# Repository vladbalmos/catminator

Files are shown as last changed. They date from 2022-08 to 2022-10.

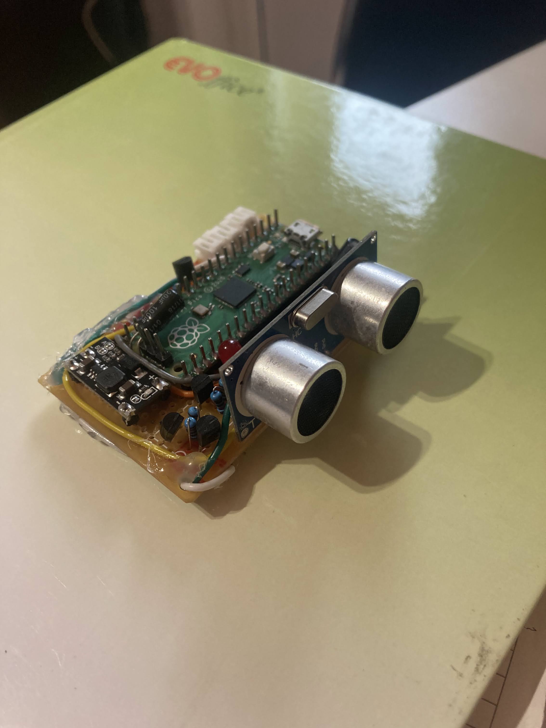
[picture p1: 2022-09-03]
docs/perfboard.jpg

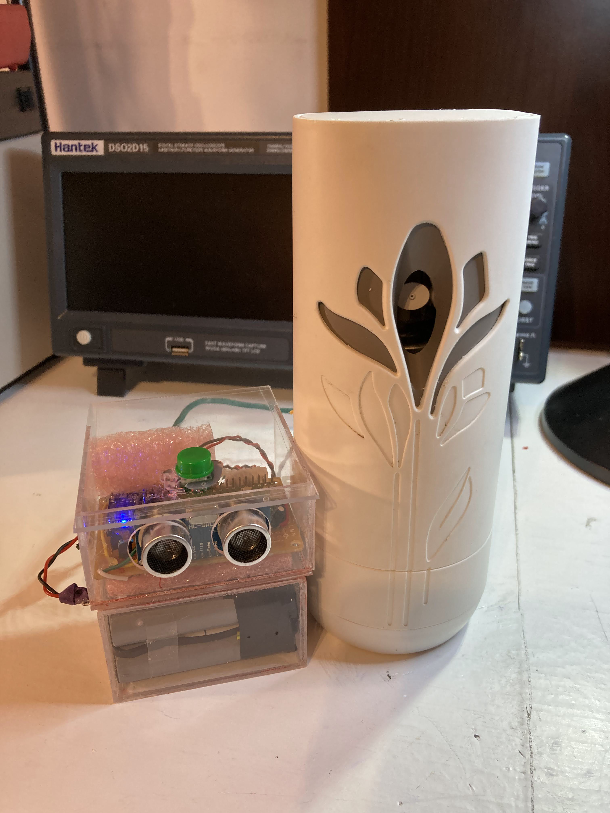
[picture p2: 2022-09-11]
docs/final-prototype.jpg

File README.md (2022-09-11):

# About
This is an educational Raspberry Pico project.  
The Pico makes use of a distance sensor to detect any objects/animals/human (preferably a cat) then drives the motors (TP7 & TP8) of an AirWick unit to spray the detected object in the hopes to scare it away.

Components: 

    - Distance sensor (HC-SR04)
    - AirWick Freshmatic (Code: ARW00171)
    - Raspberry Pico
    - 3.7V Lithium battery
    - 3V to 5V DC boost IC

For the full components list see the circuit schematic [docs/schematic.png](https://github.com/vladbalmos/catminator/blob/master/docs/schematic.png).  
To see which points on the AirWick's PCB need to be connected to the Pico see [docs/airwick-connections.png](https://github.com/vladbalmos/catminator/blob/master/docs/airwick-connections.png).

Thank you BigClive for reverse engineering the AirWick. [https://www.youtube.com/watch?v=4OC4U6FiJus](https://www.youtube.com/watch?v=4OC4U6FiJus).

Power usage:  

    - ~180ma (with motors active)
    - ~25ma (while scanning for targets)
    - ~12ma (standby)

## Memento

Monitoring serial port: 

    minicom -o -D /dev/ttyACM0 -b 115200

Building: 

    make debug #debug version
    make build #release version

Deploy: 

    make install-debug #debug version
    make install #release version

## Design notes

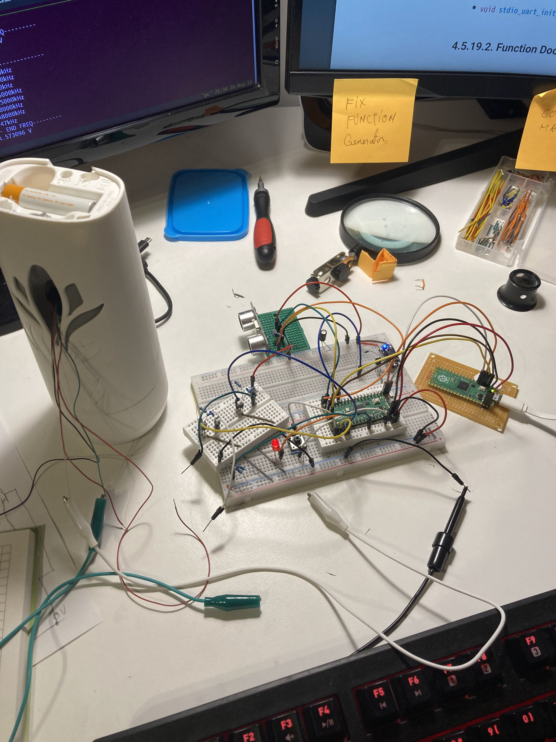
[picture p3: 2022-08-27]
docs/breadboard-prototype.jpg

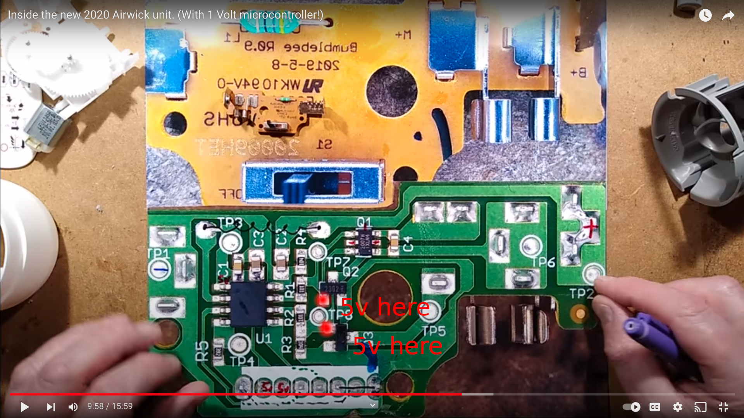
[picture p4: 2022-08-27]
docs/airwick-connections.png

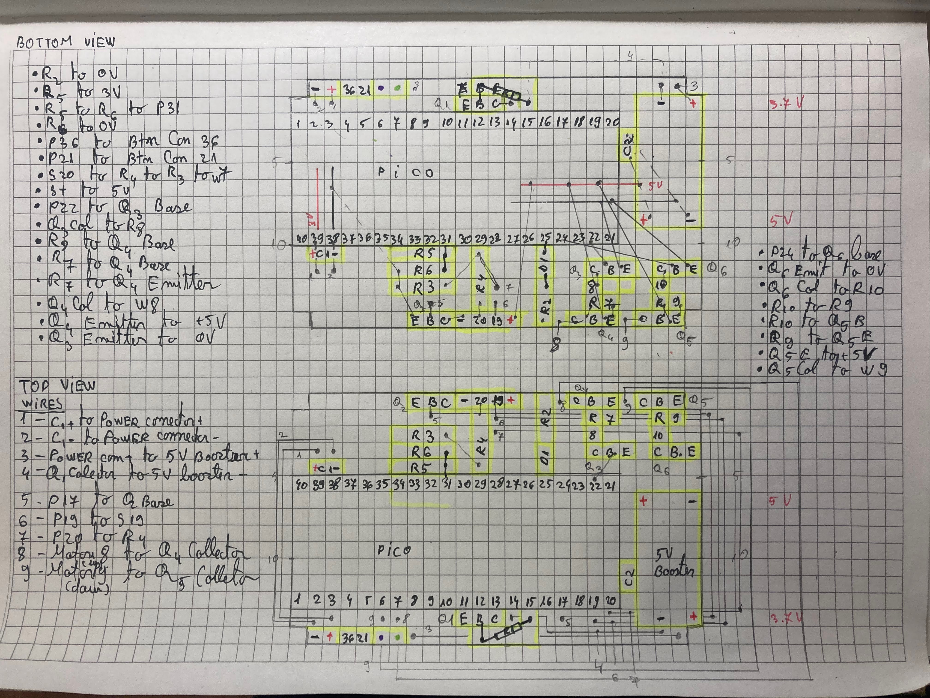
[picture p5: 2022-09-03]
docs/perfboard-layout.jpg

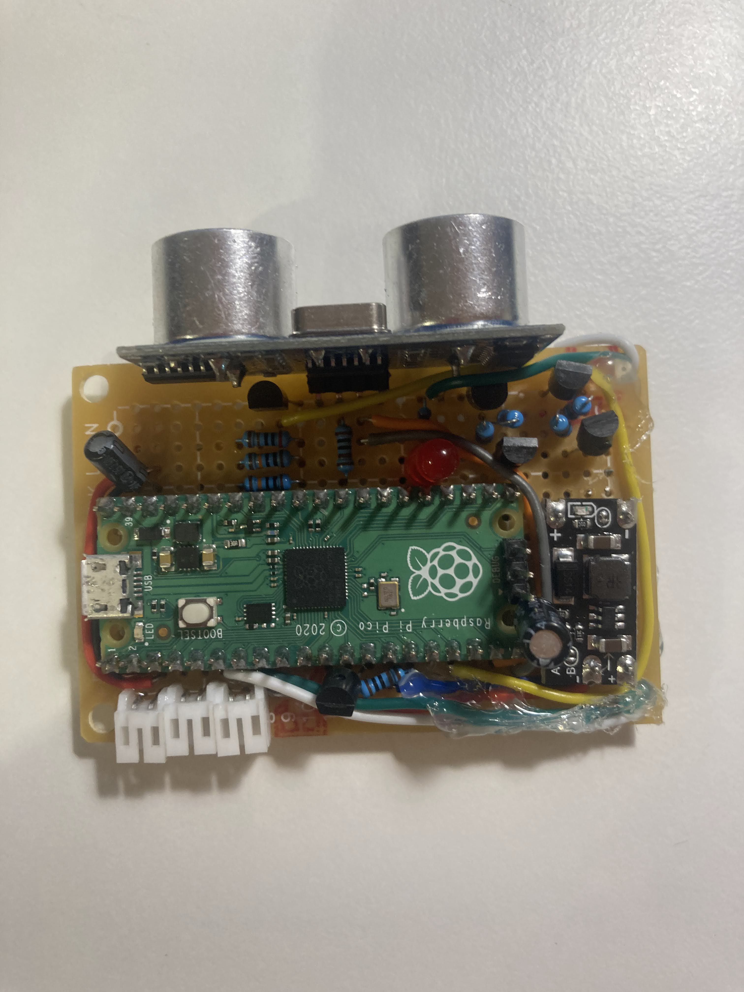
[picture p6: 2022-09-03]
docs/perfboard-side-up.jpg

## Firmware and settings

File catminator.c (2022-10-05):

/**
 * Copyright (c) 2022 Vlad Balmos
 *
 * SPDX-License-Identifier: MIT License
 */

#include <stdio.h>
#include "pico/stdlib.h"
#include "pico/util/queue.h"
#include "pico/multicore.h"
#include "hardware/pll.h"
#include "hardware/clocks.h"
#include "hardware/xosc.h"
#include "hardware/structs/pll.h"
#include "hardware/structs/clocks.h"
#include "utils.h"
#include "sensor.h"
#include "motor.h"
#include "battery.h"

#define COOL_OFF_PERIOD 10 * 1000 // seconds
#define MOTOR_DRIVE_DELAY 5000
#define DEFAULT_LOOP_SLEEP 1000
#define MAX_TARGET_DISTANCE 50 // cm

// Pins
#define SENSOR_POWER_PIN 13
#define SENSOR_INPUT_PIN 14
#define SENSOR_REPLY_PIN 15
#define BTN_CANCEL_TRIGGER_PIN 16
#define MOTOR_UP_PIN 17
#define MOTOR_DOWN_PIN 18
#define STATUS_LED_PIN 19
#define BOOST_5V_ENABLE_PIN 11

queue_t sensor_request_q;
queue_t sensor_response_q;
absolute_time_t cool_off;
bool clear_motor_drive_alarm = false;


void core1_entry() {
    while (true) {
        bool request;
        int64_t response = -1;

        queue_remove_blocking(&sensor_request_q, &request);

        if (!request) {
            sleep_ms(100);
            continue;
        }

        absolute_time_t start = nil_time;
        absolute_time_t end = nil_time;

        sensor_trigger_echo();
        sensor_measure_reply(&start, &end);

        if (start != nil_time && end != nil_time) {
            response = absolute_time_diff_us(start, end);
        }
        queue_add_blocking(&sensor_response_q, &response);
    }
}

bool is_cooling_off() {
    return cool_off != nil_time && absolute_time_diff_us(get_absolute_time(), cool_off) > 0;
}

void gpio_callback(uint gpio, uint32_t events) {
    if (gpio == BTN_CANCEL_TRIGGER_PIN && !is_cooling_off()) {
        clear_motor_drive_alarm = true;
        return;
    }
}

void measure_freqs(void) {
    uint f_pll_sys = frequency_count_khz(CLOCKS_FC0_SRC_VALUE_PLL_SYS_CLKSRC_PRIMARY);
    uint f_pll_usb = frequency_count_khz(CLOCKS_FC0_SRC_VALUE_PLL_USB_CLKSRC_PRIMARY);
    uint f_rosc = frequency_count_khz(CLOCKS_FC0_SRC_VALUE_ROSC_CLKSRC);
    uint f_clk_sys = frequency_count_khz(CLOCKS_FC0_SRC_VALUE_CLK_SYS);
    uint f_clk_peri = frequency_count_khz(CLOCKS_FC0_SRC_VALUE_CLK_PERI);
    uint f_clk_usb = frequency_count_khz(CLOCKS_FC0_SRC_VALUE_CLK_USB);
    uint f_clk_adc = frequency_count_khz(CLOCKS_FC0_SRC_VALUE_CLK_ADC);
    uint f_clk_rtc = frequency_count_khz(CLOCKS_FC0_SRC_VALUE_CLK_RTC);

    printf("------------------- FREQ-------------\n");
    printf("\tll_sys  = %dkHz\n", f_pll_sys);
    printf("\tpll_usb  = %dkHz\n", f_pll_usb);
    printf("\trosc     = %dkHz\n", f_rosc);
    printf("\tclk_sys  = %dkHz\n", f_clk_sys);
    printf("\tclk_peri = %dkHz\n", f_clk_peri);
    printf("\tclk_usb  = %dkHz\n", f_clk_usb);
    printf("\tclk_adc  = %dkHz\n", f_clk_adc);
    printf("\tclk_rtc  = %dkHz\n", f_clk_rtc);
    printf("------------------- END FREQ---------\n");
}

void stop() {
    gpio_put(BOOST_5V_ENABLE_PIN, 0);
    gpio_put(SENSOR_POWER_PIN, 0);
    if (debug_mode()) {
        gpio_put(PICO_DEFAULT_LED_PIN, 0);
    }

    clock_configure(clk_ref,
                    CLOCKS_CLK_REF_CTRL_SRC_VALUE_ROSC_CLKSRC_PH,
                    0,
                    1 * MHZ,
                    1 * MHZ);
    clock_configure(clk_sys,
                    CLOCKS_CLK_SYS_CTRL_SRC_VALUE_CLK_REF,
                    0,
                    1 * MHZ,
                    1 * MHZ);
    // Stop clocks
    xosc_disable();
    clock_stop(clk_peri);
    clock_stop(clk_usb);
    clock_stop(clk_adc);
    clock_stop(clk_rtc);
    pll_deinit(pll_sys);
    pll_deinit(pll_usb);
    clock_stop(clk_sys);
    clock_stop(clk_ref);
    panic("Stoping\n");
}

int main() {
    bool cool_off_after_motor_drive = false;

    stdio_init_all();

    if (!debug_mode()) {
        set_sys_clock_pll(756 * MHZ, 7, 6);
        clock_stop(clk_peri);
        clock_stop(clk_usb);
    }

    init_battery_readings();

    queue_init(&sensor_request_q, sizeof(bool), 1);
    queue_init(&sensor_response_q, sizeof(int64_t), 1);

    bool default_led_state = true;
    if (debug_mode()) {
        gpio_init(PICO_DEFAULT_LED_PIN);
        gpio_set_dir(PICO_DEFAULT_LED_PIN, GPIO_OUT);
    }

    // GPIO init
    gpio_init(BTN_CANCEL_TRIGGER_PIN);
    gpio_set_dir(BTN_CANCEL_TRIGGER_PIN, GPIO_IN);

    gpio_init(BOOST_5V_ENABLE_PIN);
    gpio_set_dir(BOOST_5V_ENABLE_PIN, GPIO_OUT);
    gpio_put(BOOST_5V_ENABLE_PIN, 1);

    sensor_init_pins(SENSOR_POWER_PIN, SENSOR_INPUT_PIN, SENSOR_REPLY_PIN);
    motor_init_pins(MOTOR_UP_PIN, MOTOR_DOWN_PIN);
    status_led_init(STATUS_LED_PIN);

    // Enable irq
    gpio_set_irq_enabled_with_callback(BTN_CANCEL_TRIGGER_PIN, GPIO_IRQ_EDGE_RISE, true, &gpio_callback);

    sleep_ms(5);
    multicore_launch_core1(core1_entry);
    sleep_ms(10); // Wait a bit for the core to initialize

    DEBUG("Initialized\n");
    cool_off = nil_time;

    while (true) {
        if (cool_off_after_motor_drive && !motor_is_running()) {
            cool_off = make_timeout_time_ms(COOL_OFF_PERIOD);
            cool_off_after_motor_drive = false;
            DEBUG("Cooling off after motor drive\n");
        }

        if (debug_mode()) {
            measure_freqs();
        }

        if (low_battery()) {
            DEBUG("Please recharge battery\n");
            stop();
        }

        if (debug_mode()) {
            gpio_put(PICO_DEFAULT_LED_PIN, default_led_state);
            default_led_state = !default_led_state;
        }
        if (is_cooling_off()) {
            DEBUG("Cooling off\n");
            sleep_ms(DEFAULT_LOOP_SLEEP);
            continue;
        }

        cool_off = nil_time;

        if (clear_motor_drive_alarm && motor_is_drive_scheduled()) {
            DEBUG("Canceling drive requested\n");
            clear_motor_drive_alarm = false;
            motor_cancel_drive();
            cool_off = make_timeout_time_ms(COOL_OFF_PERIOD);
            sleep_ms(DEFAULT_LOOP_SLEEP);
            continue;
        }


        if (queue_is_full(&sensor_request_q)) {
            DEBUG("Request queue is full. Sleeping\n");
            sleep_ms(DEFAULT_LOOP_SLEEP);
            continue;
        }

        if (motor_is_running()) {
            sleep_ms(DEFAULT_LOOP_SLEEP);
            cool_off_after_motor_drive = true;
            continue;
        }

        sensor_toggle_power(true);
        int distance = sensor_read(&sensor_request_q, &sensor_response_q);
        sensor_toggle_power(false);
        DEBUG("Target distance: %dcm \n", distance);

        if (distance < 0) {
            sleep_ms(DEFAULT_LOOP_SLEEP);
            continue;
        }

        if (distance < MAX_TARGET_DISTANCE && !motor_is_drive_scheduled()) {
            motor_schedule_drive(MOTOR_DRIVE_DELAY);
            DEBUG("Target aquired. Scheduling motor drive\n");
        } else if (distance >= MAX_TARGET_DISTANCE)  {
            if (motor_is_drive_scheduled()) {
                DEBUG("Target lost. Canceling motor drive\n");
                motor_cancel_drive();
            }
        }
        sleep_ms(DEFAULT_LOOP_SLEEP);
    }

    return 0;
}

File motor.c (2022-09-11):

/**
 * Copyright (c) 2022 Vlad Balmos
 *
 * SPDX-License-Identifier: MIT License
 */

#include <stdlib.h>
#include "pico/stdlib.h"
#include "motor.h"
#include "utils.h"

#define MOTOR_DRIVE_DURATION 690
#define MOTOR_DRIVE_REVERSAL_DURATION 200
#define MOTOR_PAUSE_BEFORE_REVERSAL 200

typedef struct {
    uint pin;
    uint drive_duration;
} motor_state;

bool motor_drive_scheduled = false;
bool motor_running = false;
uint up_pin;
uint down_pin;
alarm_id_t motor_drive_up_alarm = 0;
motor_state* mstate;

void motor_init_pins(uint upin, uint dpin) {
    up_pin = upin;
    down_pin = dpin;

    gpio_init(up_pin);
    gpio_set_dir(up_pin, GPIO_OUT);
    gpio_pull_down(up_pin);

    gpio_init(down_pin);
    gpio_set_dir(down_pin, GPIO_OUT);
    gpio_pull_down(down_pin);
}

int64_t start_drive_motor(alarm_id_t id, void *user_data) {
    if (!motor_running) {
        motor_running = true;
        status_led_toggle(true);
    }
    motor_state *state = (motor_state *) user_data;

    DEBUG("Driving motor on PIN %d\n", state->pin);
    gpio_put(state->pin, 1);
    add_alarm_in_ms(state->drive_duration, stop_drive_motor, user_data, false);

    return 0;
}

int64_t stop_drive_motor(alarm_id_t id, void *user_data) {
    motor_state *state = (motor_state *) user_data;
    gpio_put(state->pin, 0);

    if (state->pin == up_pin) {
        state->pin = down_pin;
        state->drive_duration = MOTOR_DRIVE_REVERSAL_DURATION;
        add_alarm_in_ms(MOTOR_PAUSE_BEFORE_REVERSAL, start_drive_motor, (void *)state, false);
        return 0;
    }
    free(mstate);
    mstate = NULL;
    motor_drive_scheduled = false;
    motor_running = false;
    status_led_toggle(false);
    return 0;
}

bool motor_is_drive_scheduled() {
    return motor_drive_scheduled;
}

void motor_schedule_drive(uint delay) {
    if (motor_drive_scheduled) {
        return;
    }

    mstate = malloc(sizeof(motor_state));
    mstate->pin = up_pin;
    mstate->drive_duration = MOTOR_DRIVE_DURATION;
    motor_drive_scheduled = true;
    motor_drive_up_alarm = add_alarm_in_ms(delay, start_drive_motor, (void *)mstate, false);

    if (motor_drive_up_alarm == -1) {
        // TODO: flash error LED
        return;
    }
    status_led_toggle(true);
}

void motor_cancel_drive() {
    if (!motor_drive_up_alarm) {
        return;
    }

    free(mstate);
    mstate = NULL;
    cancel_alarm(motor_drive_up_alarm);
    motor_drive_up_alarm = 0;
    motor_drive_scheduled = false;
    status_led_toggle(false);
}

bool motor_is_running() {
    return motor_running;
}

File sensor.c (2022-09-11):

/**
 * Copyright (c) 2022 Vlad Balmos
 *
 * SPDX-License-Identifier: MIT License
 */

#include <stdio.h>
#include "pico/stdlib.h"
#include "pico/util/queue.h"
#include "sensor.h"

uint power_pin,
     input_pin,
     reply_pin;

void sensor_init_pins(uint ppin, uint ipin, uint opin) {
    power_pin = ppin;
    input_pin = ipin;
    reply_pin = opin;

    gpio_init(power_pin);
    gpio_set_dir(power_pin, GPIO_OUT);
    gpio_pull_down(power_pin);

    gpio_init(input_pin);
    gpio_set_dir(input_pin, GPIO_OUT);
    gpio_pull_down(input_pin);

    gpio_init(reply_pin);
    gpio_set_dir(reply_pin, GPIO_IN);
    gpio_pull_down(reply_pin);
}

void sensor_toggle_power(bool state) {
    gpio_put(power_pin, state);
    sleep_ms(10); // Wait for the sensor to initialize/power down
}

int sensor_read(queue_t *in_q, queue_t *out_q) {
    bool request = true;
    int64_t sensor_response = -1;

    queue_add_blocking(in_q, &request);
    queue_remove_blocking(out_q, &sensor_response);

    if (sensor_response < 0) {
        return -1;
    }

    int64_t response = sensor_response / 58;
    return (int) response;
}

void sensor_trigger_echo() {
    gpio_put(input_pin, 1);
    sleep_us(11);
    gpio_put(input_pin, 0);
}

void sensor_measure_reply(absolute_time_t *start, absolute_time_t *end) {
    absolute_time_t max_timeout = make_timeout_time_us(100000);
    bool prev_state = false;
    bool current_state = false;

    while (absolute_time_diff_us(get_absolute_time(), max_timeout) > 0) {
        current_state = gpio_get(reply_pin);

        // No activity on reply pin
        if (!current_state && !prev_state) {
            sleep_us(1);
            continue;
        }

        // Rising edge detected on reply pin
        if (current_state && !prev_state) {
            *start = get_absolute_time();
            prev_state = current_state;
            sleep_us(1);
            continue;
        }

        // Falling edge detected on reply pin
        if (!current_state && prev_state) {
            *end = get_absolute_time();
            return;
        }

        // Reply pin is HIGH
        if (current_state && prev_state) {
            sleep_us(1);
        }
    }
}

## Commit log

2022-07-28 Remove print statements
2022-07-29 Update motor values
2022-08-23 Reduce power on production build
2022-08-27 Add schematic
2022-08-28 Add more images
    [layout.fzz, pcb.fzz]
2022-09-03 Lower power usage on halt. Add more docs
    [layout.fzz, pcb.fzz]
2022-09-11 Add final prototype picture
2022-09-11 Update power consumption data
2022-10-05 Shorten max target distance
    [catminator.c]
